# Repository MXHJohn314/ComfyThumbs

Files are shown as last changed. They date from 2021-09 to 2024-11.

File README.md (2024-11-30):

# ComfyThumbs

A column-staggered keyboard inspired by comfortable and efficient thumb use and keycap compatibility.

### The Default Keymap
<h5><b>Comfy Thumbs (v3)</b></h5>

[Check out the Gist on Keyboard Layout Editor](http://www.keyboard-layout-editor.com/#/gists/36e706f383088aca6e862086f8b5e326)
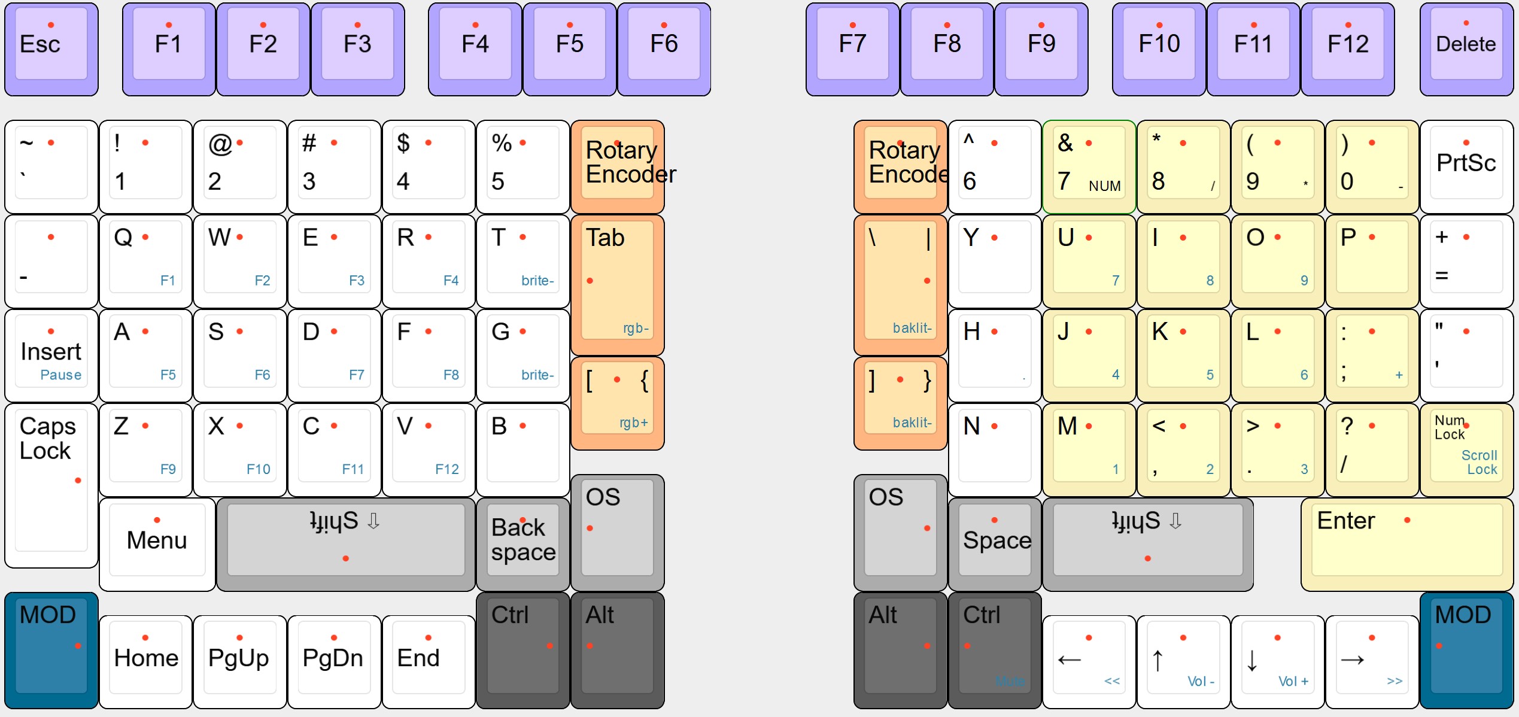
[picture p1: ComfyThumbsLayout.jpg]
Default Keymap

<p>

### High Keycap Compatibility

Comfy Thumbs has the highest keycap compatibility of any column-staggered board. Space and Backspace are the only keys that are not traditionally-sized. That means you won't need to buy/use different keycaps for `Right Shift`, `Left Shift`, `Enter`, `Tab`, `\ `, `Command`, `Ctrl`, `Alt`, `OS`, and `Application` keys. Just chose any Standard ANSI keycap set (99% of keycap sets), and you're good to go!. 

<p>

### Use your thumbs without hurting them

|Thumb Cluster Style|# of keys|Avg. reach from Home Position|
|---|---|---|
|ComfyThumbs|6|1u
|Manuform/Dactyl-Manuform|6|3.5u
|Maltron/Dacyl/Kenesis/Ergodox|6-8|4.5u

Unlike other large thumb cluster designs that waste valuable space by pushing the cluster away from resting thumb position or building the cluster on a convex plane, all thumb keys are within 1u radius of resting position. The thumbs naturally rest on either `Space` or `Backspace`, with `Shift`, `Ctrl`, `Alt` and `OS` nearby. There are two thumb rows; `Space`, `Backspace`, and both `Shift` keys have a higher profile on the upper thumb row to distinguish thumb location by feel.

### Comfy Thumbs = Comfy Pinkies
Your pinkies have been doing way more work than they should. That's why modifiers have moved to the thumb cluster. Adding to that, the index fingers have a new inner column for `Tab`, `\ `, `-`, `=`,  `[` and `]`.

Keyboard Maintainer: [MXHJohn314](https://mxhjohn314.github.io/)  

### Compiling the Firmware

See the [build environment setup](Todo) and the [make instructions](Todo) for more information. Brand new to ZMK? Start with our [Complete Newbs Guide](Todo).

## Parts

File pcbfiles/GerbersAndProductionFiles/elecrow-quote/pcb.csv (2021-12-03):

Id | Designator | Package | Quantity | Designation | Source/Manufacturer | Part # | Can substitute?
1 | SW59,SW82,SW2,SW56,SW20,SW3,SW11,SW61,SW78,SW89,SW52,SW67,SW41,SW72,SW88,SW87,SW86,SW85,SW83,SW81,SW80,SW79,SW77,SW76,SW75,SW74,SW71,SW70,SW69,SW68,SW65,SW64,SW63,SW62,SW60,SW58,SW57,SW55,SW54,SW53,SW49,SW48,SW39,SW37,SW36,SW35,SW34,SW33,SW31,SW30,SW29,SW28,SW27,SW25,SW24,SW23,SW22,SW21,SW19,SW18,SW17,SW16,SW15,SW14,SW13,SW12,SW10,SW9,SW8,SW7,SW6,SW5,SW4 | MXOnly-1U-Hotswap | 73 | SW_SPST | Kailhua | CPG151101S11 | No
6 | SW51 | MXOnly-2U-Hotswap-VerticalStabilizers | 1 | SW_SPST | Kailhua | CPG151101S11 | No
17 | SW73 | MXOnly-2.75U-Hotswap-ReversedStabilizers | 1 | SW_SPST | Kailhua | CPG151101S11 | No
18 | SW43 | MXOnly-1.75U-Hotswap | 1 | SW_SPST | Kailhua | CPG151101S11 | No
15 | SW91,SW90,SW84,SW45,SW40,SW32,SW42 | MXOnly-1.25U-Hotswap | 7 | SW_SPST | Kailhua | CPG151101S11 | No
19 | SW26 | MXOnly-2.25U-Hotswap-ReversedStabilizers | 1 | SW_SPST | Kailhua | CPG151101S11 | No
4 | SW44,SW50 | MXOnly-1.5U-Hotswap | 2 | SW_SPST | Kailhua | CPG151101S11 | No
2 | J10,J9,J5,J4 | JST_SH_SM05B-SRSS-TB_1x05-1MP_P1.00mm_Horizontal | 4 | Conn_01x05 | Japan Solderless Technologies | SM05B-SRSS-TB | No
5 | SW1,SW66 | SW_SPST_TL3342 | 2 | SW_SPST | E-Switch | TL3342F320QG | Yes
7 | U1,U4 | nRF52840_holyiot_18010_HS_simple | 2 | nRF52840_holyiot_18010 | I will source and supply these parts to Elecrow, for you to assemble. |  | N/A
8 | BT3,BT1 | JST_PH_S2B-PH-K_1x02_P2.00mm_Horizontal | 2 | Battery_Cell | Japan Solderless Technologies | S2B-PH-K-S | No
11 | D1,D60 | D_SOD-123 | 2 | 1N5819 | YFW | 1N5819W | Yes
12 | R15,R8 | R_0805_2012Metric | 2 | 2M | FH(Guangdong Fenghua Advanced Tech) | RS-05L2004FT | Yes
13 | R12,R16,R3,R2 | R_0805_2012Metric | 4 | 10k | RC0805JR-0710KL | YAGEO | Yes
16 | D56,D92,D91,D90,D89,D88,D87,D86,D85,D84,D83,D82,D81,D80,D79,D78,D77,D76,D75,D74,D73,D72,D71,D70,D69,D68,D67,D66,D65,D64,D63,D62,D61,D59,D58,D57,D55,D54,D53,D52,D51,D50,D49,D46,D45,D44,D43,D42,D41,D38,D37,D36,D35,D34,D33,D32,D31,D30,D29,D28,D27,D26,D25,D24,D23,D22,D21,D20,D19,D18,D17,D16,D15,D14,D13,D12,D11,D10,D9,D8,D7,D6,D5,D4,D3,D2 | D_SOD-123 | 86 | D_Small | MDD（Microdiode Electronics） | SM4007PL | Yes
20 | USB2,USB1 | HRO-TYPE-C-31-M-12-HandSoldering | 2 | HRO-TYPE-C-31-M-12 | Korean Hroparts Elec | TYPE-C-31-M-12 | No
21 | U6,U2 | SOT-23 | 2 | XC6206 | Torex Semicon | XC6206P332MR | Yes
22 | U5,U3 | SOT-23-5 | 2 | TP4054 | UMW(Youtai Semiconductor Co., Ltd.) | TP4054 | Yes
23 | SW47,SW38 | SW_SPDT_PCM12 | 2 | SW_SPDT | C&K | PCM12SMTR | Yes
24 | R14,R9 | R_0805_2012Metric | 2 | 1k | Resistor.Today | AECR0805F1K00K9 | Yes
25 | R13,R7 | R_0805_2012Metric | 2 | 806k | Walsin Tech Corp | WR08X8063FTL | Yes
26 | R11,R10,R5,R1 | R_0805_2012Metric | 4 | 5.1k | YAGEO | RC0805JR-075K1L | Yes
27 | R6,R4 | R_0805_2012Metric | 2 | 1M | TyoHM | RMC 0805 1M F N | Yes
28 | Q2,Q1 | SOT-23 | 2 | AO3401A | VBsemi Elec | AO3401A | Yes
29 | F2,F1 | Fuse_1206_3216Metric | 2 | 500ma | Littelfuse | 1206L050/15YR | Yes
30 | D48,D39 | D_0805_2012Metric | 2 | LED_Small | Hubei KENTO Elec | 17-21SUYC/TR8 | Yes
31 | D47,D40 | SOT-143 | 2 | SR05 | Leiditech | SR05 | Yes
32 | C8,C7,C4,C3 | C_0805_2012Metric | 4 | 1uF | Samsung Electro-Mechanics | CL21B105KBFNNNE | Yes
33 | C6,C1 | C_0805_2012Metric | 2 | 4.7uF | Samsung Electro-Mechanics | CL21B475KAFNNNE | Yes
34 | C5,C2 | C_0805_2012Metric | 2 | 4.7n | FH(Guangdong Fenghua Advanced Tech) | 0805B472K500NT | Yes

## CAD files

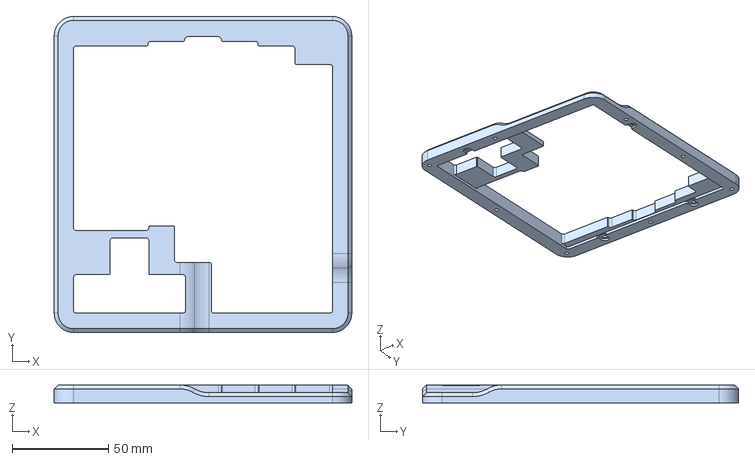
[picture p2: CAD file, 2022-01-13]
casefiles/case/left/TOP-LEFT-ComfyHands_prototype_13Jan.step
154.3 x 163.8 x 9.30 mm

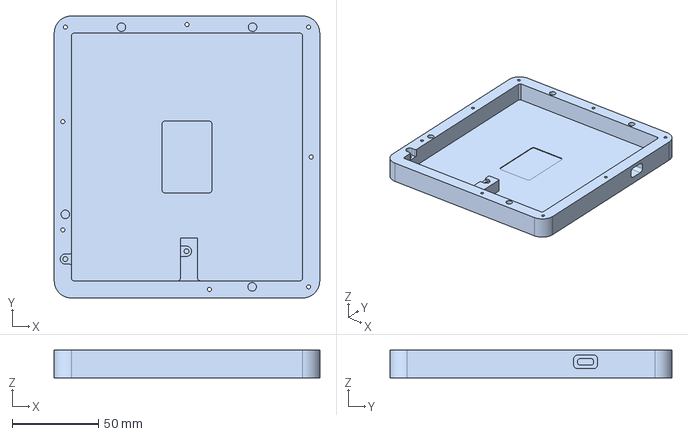
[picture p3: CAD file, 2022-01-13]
casefiles/case/right/BOTTOM-RIGHT-ComfyHands_prototype_13Jan.step
154.3 x 163.8 x 16.0 mm

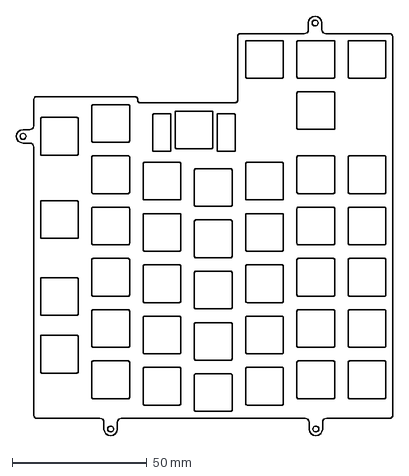
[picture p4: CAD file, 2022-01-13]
casefiles/plates/dxf/plate_left.dxf
139.8 x 155.9 mm

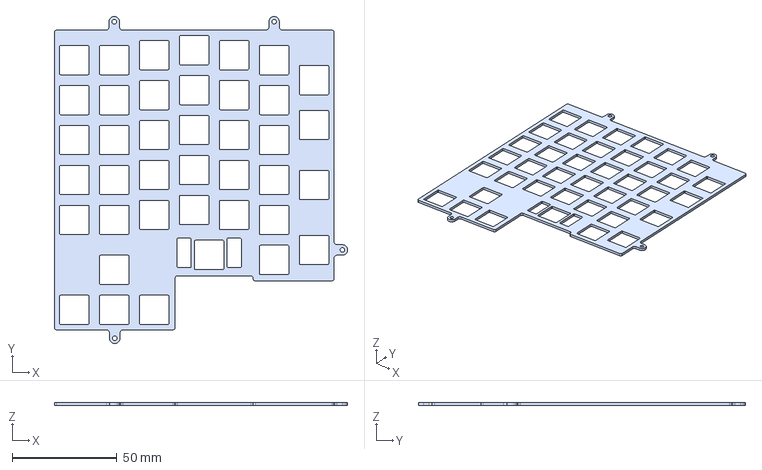
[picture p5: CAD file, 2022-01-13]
casefiles/plates/step/PLATE_LEFT-ComfyHands_prototype_13Jan.step
139.8 x 155.9 x 1.50 mm

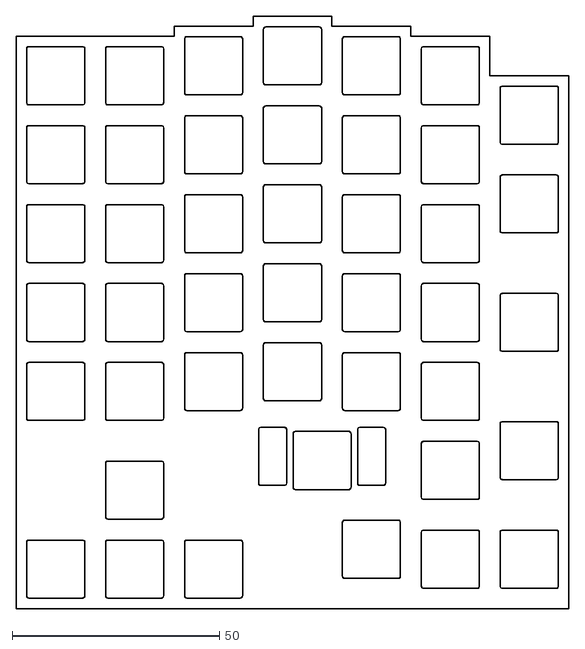
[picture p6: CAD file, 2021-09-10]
pcbfiles/plate-Edge_Cuts.dxf
133.3 x 142.9

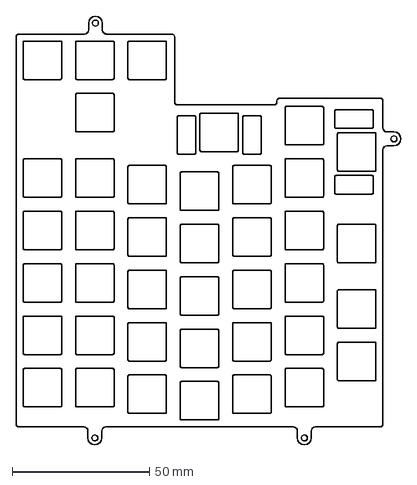
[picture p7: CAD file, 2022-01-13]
casefiles/plates/dxf/plate_right.dxf
139.8 x 155.9 mm

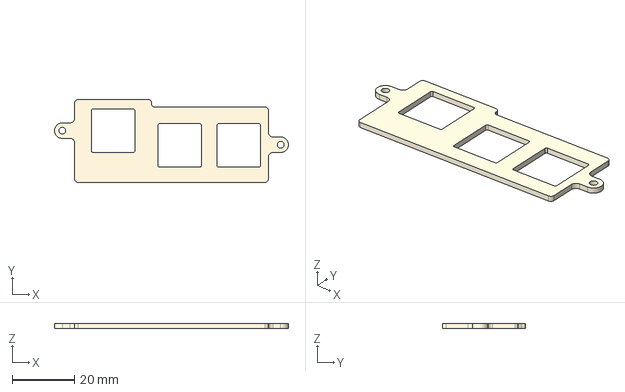
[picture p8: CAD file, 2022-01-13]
casefiles/plates/step/PLATE_SMALL-ComfyHands_prototype_13Jan.step
75.4 x 26.7 x 1.50 mm

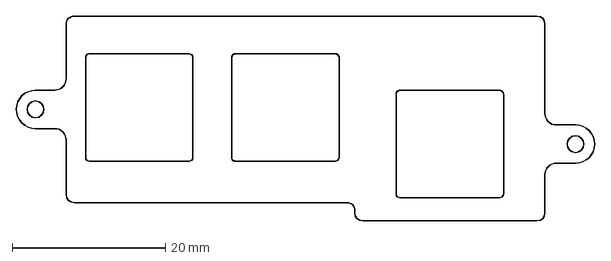
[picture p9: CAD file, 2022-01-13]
casefiles/plates/dxf/plate_small.dxf
75.4 x 26.7 mm

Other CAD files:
casefiles/case/left/BOTTOM-LEFT-ComfyHands_prototype_13Jan.step
casefiles/case/right/TOP-RIGHT-ComfyHands_prototype_13Jan.step
casefiles/plates/step/PLATE-RIGHT-ComfyHands_prototype_13Jan.step
casefiles/case/project.f3z

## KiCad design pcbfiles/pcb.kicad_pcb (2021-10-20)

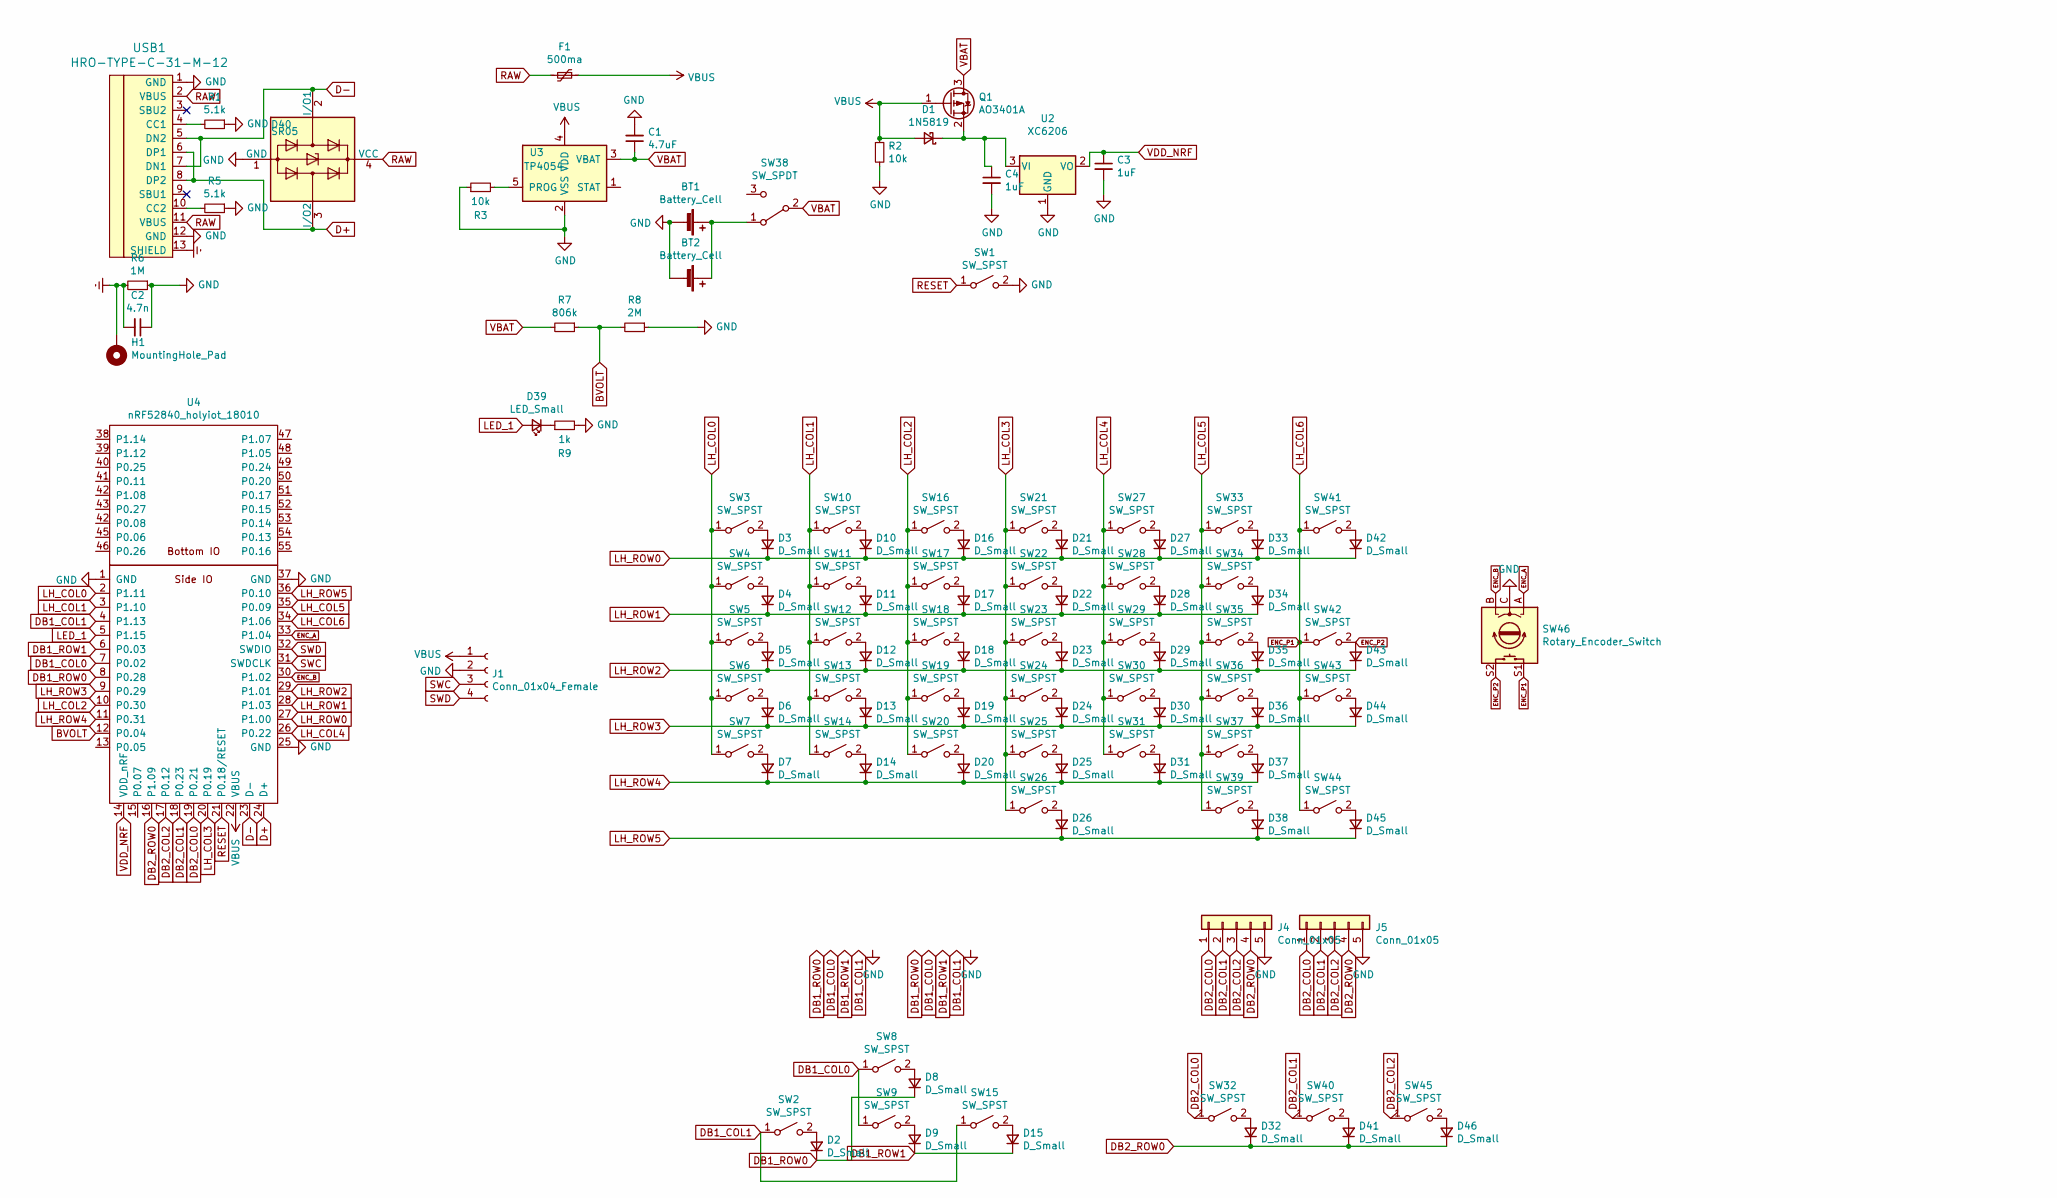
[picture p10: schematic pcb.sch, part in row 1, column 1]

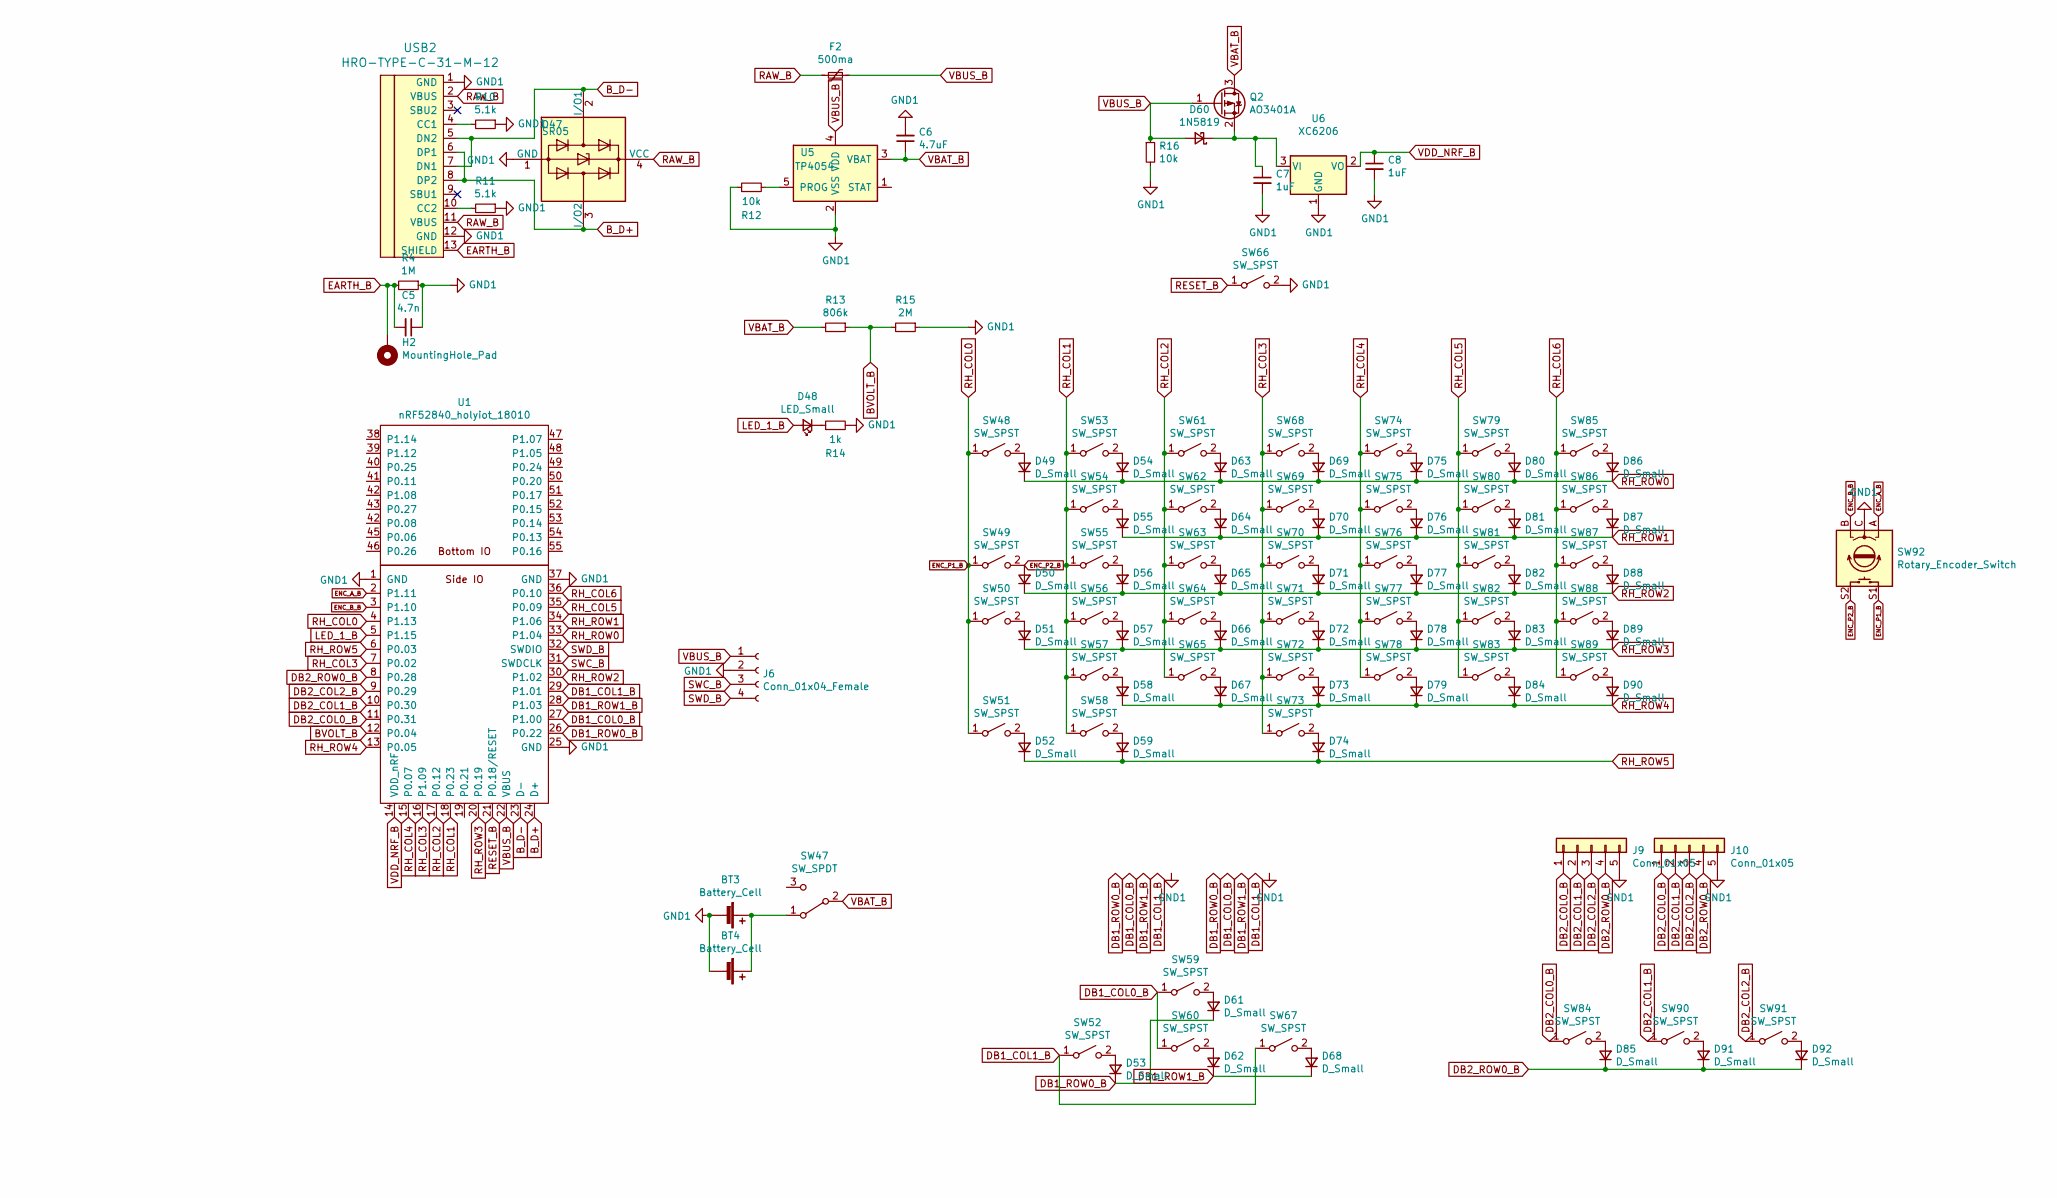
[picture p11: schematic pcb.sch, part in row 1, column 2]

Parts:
BT1, BT3: Battery_Cell; JST_PH_S2B-PH-K_1x02_P2.00mm_Horizontal
BT2, BT4: Battery_Cell; battery-custom-connector
C1, C6: 4.7uF; C_0805_2012Metric
C2, C5: 4.7n; C_0805_2012Metric
C3, C4, C7, C8: 1uF; C_0805_2012Metric
D1, D60: 1N5819; D_SOD-123
D2, D3, D4, D5, D6, D7, D8, D9, D10, D11, D12, D13, D14, D15, D16, D17, D18, D19, D20, D21, D22, D23, D24, D25, D26, D27, D28, D29, D30, D31, D32, D33, D34, D35, D36, D37, D38, D41, D42, D43, D44, D45, D46, D49, D50, D51, D52, D53, D54, D55, D56, D57, D58, D59, D61, D62, D63, D64, D65, D66, D67, D68, D69, D70, D71, D72, D73, D74, D75, D76, D77, D78, D79, D80, D81, D82, D83, D84, D85, D86, D87, D88, D89, D90, D91, D92: D_Small; D_SOD-123
D39, D48: LED_Small; D_0805_2012Metric
D40, D47: SR05; SOT-143
F1, F2: 500ma; Fuse_1206_3216Metric
H1, H2: MountingHole_Pad
J1, J6: Conn_01x04_Female; PinHeader_1x04_P2.54mm_Vertical
J4, J5, J9, J10: Conn_01x05; JST_SH_SM05B-SRSS-TB_1x05-1MP_P1.00mm_Horizontal
Q1, Q2: AO3401A; SOT-23
R1, R5, R10, R11: 5.1k; R_0805_2012Metric
R2, R3, R12, R16: 10k; R_0805_2012Metric
R4, R6: 1M; R_0805_2012Metric
R7, R13: 806k; R_0805_2012Metric
R8, R15: 2M; R_0805_2012Metric
R9, R14: 1k; R_0805_2012Metric
SW1, SW66: SW_SPST; SW_SPST_TL3342
SW2, SW3, SW4, SW5, SW6, SW7, SW8, SW9, SW10, SW11, SW12, SW13, SW14, SW15, SW16, SW17, SW18, SW19, SW20, SW21, SW22, SW23, SW24, SW25, SW27, SW28, SW29, SW30, SW31, SW33, SW34, SW35, SW36, SW37, SW39, SW41, SW48, SW49, SW52, SW53, SW54, SW55, SW56, SW57, SW58, SW59, SW60, SW61, SW62, SW63, SW64, SW65, SW67, SW68, SW69, SW70, SW71, SW72, SW74, SW75, SW76, SW77, SW78, SW79, SW80, SW81, SW82, SW83, SW85, SW86, SW87, SW88, SW89: SW_SPST; MXOnly-1U-Hotswap
SW26: SW_SPST; MXOnly-2.25U-Hotswap-ReversedStabilizers
SW32, SW40, SW42, SW45, SW84, SW90, SW91: SW_SPST; MXOnly-1.25U-Hotswap
SW38, SW47: SW_SPDT; SW_SPDT_PCM12
SW43: SW_SPST; MXOnly-1.75U-Hotswap
SW44, SW50: SW_SPST; MXOnly-1.5U-Hotswap
SW46, SW92: Rotary_Encoder_Switch; RotaryEncoder_Alps_EC11E-Switch_Vertical_H20mm
SW51: SW_SPST; MXOnly-2U-Hotswap-VerticalStabilizers
SW73: SW_SPST; MXOnly-2.75U-Hotswap-ReversedStabilizers
U1, U4: nRF52840_holyiot_18010; nRF52840_holyiot_18010_HS_simple
U2, U6: XC6206; SOT-23
U3, U5: TP4054; SOT-23-5
USB1, USB2: HRO-TYPE-C-31-M-12; HRO-TYPE-C-31-M-12-HandSoldering

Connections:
BVOLT: R7.1, R8.2, U4.12 (P0.04)
BVOLT_B: R13.1, R15.2, U1.12 (P0.04)
B_D+: D47.3 (I/O2), U1.24 (D+), USB2.6 (DP1), USB2.8 (DP2)
B_D-: D47.2 (I/O1), U1.23 (D-), USB2.5 (DN2), USB2.7 (DN1)
D+: D40.3 (I/O2), U4.24 (D+), USB1.6 (DP1), USB1.8 (DP2)
D-: D40.2 (I/O1), U4.23 (D-), USB1.5 (DN2), USB1.7 (DN1)
DB1_COL0: SW8.1 (A), SW9.1 (A), U4.7 (P0.02)
DB1_COL0_B: SW59.1 (A), SW60.1 (A), U1.27 (P1.00)
DB1_COL1: SW2.1 (A), SW15.1 (A), U4.4 (P1.13)
DB1_COL1_B: SW52.1 (A), SW67.1 (A), U1.29 (P1.01)
DB1_ROW0: D2.1 (K), D8.1 (K), U4.8 (P0.28)
DB1_ROW0_B: D53.1 (K), D61.1 (K), U1.26 (P0.22)
DB1_ROW1: D9.1 (K), D15.1 (K), U4.6 (P0.03)
DB1_ROW1_B: D62.1 (K), D68.1 (K), U1.28 (P1.03)
DB2_COL0: J4.1, J5.1, SW32.1 (A), U4.19 (P0.21)
DB2_COL0_B: J9.1, J10.1, SW84.1 (A), U1.11 (P0.31)
DB2_COL1: J4.2, J5.2, SW40.1 (A), U4.18 (P0.23)
DB2_COL1_B: J9.2, J10.2, SW90.1 (A), U1.10 (P0.30)
DB2_COL2: J4.3, J5.3, SW45.1 (A), U4.17 (P0.12)
DB2_COL2_B: J9.3, J10.3, SW91.1 (A), U1.9 (P0.29)
DB2_ROW0: D32.1 (K), D41.1 (K), D46.1 (K), J4.4, J5.4, U4.16 (P1.09)
DB2_ROW0_B: D85.1 (K), D91.1 (K), D92.1 (K), J9.4, J10.4, U1.8 (P0.28)
EARTH_B: C5.2, H2.1, R4.2, USB2.13 (SHIELD)
ENC_A: SW46.A, U4.33 (P1.04)
ENC_A_B: SW92.A, U1.2 (P1.11)
ENC_B: SW46.B, U4.30 (P1.02)
ENC_B_B: SW92.B, U1.3 (P1.10)
ENC_P1: SW41.1 (A), SW42.1 (A), SW43.1 (A), SW44.1 (A), SW46.S1, U4.34 (P1.06)
ENC_P1_B: SW48.1 (A), SW49.1 (A), SW50.1 (A), SW51.1 (A), SW92.S1, U1.4 (P1.13)
ENC_P2: D43.2 (A), SW42.2 (B), SW46.S2
ENC_P2_B: D50.2 (A), SW49.2 (B), SW92.S2
Earth: C2.2, H1.1, R6.2, USB1.13 (SHIELD)
GND: BT1.2 (-), BT2.2 (-), C1.2, C2.1, C3.2, C4.2, D40.1 (GND), J1.2, J4.5, J5.5, R1.1, R2.2, R3.1, R5.1, R6.1, R8.1, R9.2, SW1.2 (B), SW46.C, U2.1 (GND), U3.2 (VSS), U4.1 (GND), U4.25 (GND), U4.37 (GND), USB1.1 (GND), USB1.12 (GND)
GND1: BT3.2 (-), BT4.2 (-), C5.1, C6.2, C7.2, C8.2, D47.1 (GND), J6.2, J9.5, J10.5, R4.1, R10.1, R11.1, R12.1, R14.2, R15.1, R16.2, SW66.2 (B), SW92.C, U1.1 (GND), U1.25 (GND), U1.37 (GND), U5.2 (VSS), U6.1 (GND), USB2.1 (GND), USB2.12 (GND)
LED_1: D39.2 (A), U4.5 (P1.15)
LED_1_B: D48.2 (A), U1.5 (P1.15)
LH_COL0: SW3.1 (A), SW4.1 (A), SW5.1 (A), SW6.1 (A), SW7.1 (A), U4.2 (P1.11)
LH_COL1: SW10.1 (A), SW11.1 (A), SW12.1 (A), SW13.1 (A), SW14.1 (A), U4.3 (P1.10)
LH_COL2: SW16.1 (A), SW17.1 (A), SW18.1 (A), SW19.1 (A), SW20.1 (A), U4.10 (P0.30)
LH_COL3: SW21.1 (A), SW22.1 (A), SW23.1 (A), SW24.1 (A), SW25.1 (A), SW26.1 (A), U4.20 (P0.19)
LH_COL4: SW27.1 (A), SW28.1 (A), SW29.1 (A), SW30.1 (A), SW31.1 (A), U4.26 (P0.22)
LH_COL5: SW33.1 (A), SW34.1 (A), SW35.1 (A), SW36.1 (A), SW37.1 (A), SW39.1 (A), U4.35 (P0.09)
LH_ROW0: D3.1 (K), D10.1 (K), D16.1 (K), D21.1 (K), D27.1 (K), D33.1 (K), D42.1 (K), U4.27 (P1.00)
LH_ROW1: D4.1 (K), D11.1 (K), D17.1 (K), D22.1 (K), D28.1 (K), D34.1 (K), U4.28 (P1.03)
LH_ROW2: D5.1 (K), D12.1 (K), D18.1 (K), D23.1 (K), D29.1 (K), D35.1 (K), D43.1 (K), U4.29 (P1.01)
LH_ROW3: D6.1 (K), D13.1 (K), D19.1 (K), D24.1 (K), D30.1 (K), D36.1 (K), D44.1 (K), U4.9 (P0.29)
LH_ROW4: D7.1 (K), D14.1 (K), D20.1 (K), D25.1 (K), D31.1 (K), D37.1 (K), U4.11 (P0.31)
LH_ROW5: D26.1 (K), D38.1 (K), D45.1 (K), U4.36 (P0.10)
unnamed: BT1.1 (+), BT2.1 (+), SW38.1 (A)
unnamed: BT3.1 (+), BT4.1 (+), SW47.1 (A)
unnamed: C4.1, D1.1 (K), Q1.2 (S), U2.3 (VI)
unnamed: C7.1, D60.1 (K), Q2.2 (S), U6.3 (VI)
unnamed: D2.2 (A), SW2.2 (B)
unnamed: D3.2 (A), SW3.2 (B)
unnamed: D4.2 (A), SW4.2 (B)
unnamed: D5.2 (A), SW5.2 (B)
unnamed: D6.2 (A), SW6.2 (B)
unnamed: D7.2 (A), SW7.2 (B)
unnamed: D8.2 (A), SW8.2 (B)
unnamed: D9.2 (A), SW9.2 (B)
unnamed: D10.2 (A), SW10.2 (B)
unnamed: D11.2 (A), SW11.2 (B)
unnamed: D12.2 (A), SW12.2 (B)
unnamed: D13.2 (A), SW13.2 (B)
unnamed: D14.2 (A), SW14.2 (B)
unnamed: D15.2 (A), SW15.2 (B)
unnamed: D16.2 (A), SW16.2 (B)
unnamed: D17.2 (A), SW17.2 (B)
unnamed: D18.2 (A), SW18.2 (B)
unnamed: D19.2 (A), SW19.2 (B)
unnamed: D20.2 (A), SW20.2 (B)
unnamed: D21.2 (A), SW21.2 (B)
unnamed: D22.2 (A), SW22.2 (B)
unnamed: D23.2 (A), SW23.2 (B)
unnamed: D24.2 (A), SW24.2 (B)
unnamed: D25.2 (A), SW25.2 (B)
unnamed: D26.2 (A), SW26.2 (B)
unnamed: D27.2 (A), SW27.2 (B)
unnamed: D28.2 (A), SW28.2 (B)
unnamed: D29.2 (A), SW29.2 (B)
unnamed: D30.2 (A), SW30.2 (B)
unnamed: D31.2 (A), SW31.2 (B)
unnamed: D32.2 (A), SW32.2 (B)
unnamed: D33.2 (A), SW33.2 (B)
unnamed: D34.2 (A), SW34.2 (B)
unnamed: D35.2 (A), SW35.2 (B)
unnamed: D36.2 (A), SW36.2 (B)
unnamed: D37.2 (A), SW37.2 (B)
unnamed: D38.2 (A), SW39.2 (B)
unnamed: D39.1 (K), R9.1
unnamed: D41.2 (A), SW40.2 (B)
unnamed: D42.2 (A), SW41.2 (B)
unnamed: D44.2 (A), SW43.2 (B)
unnamed: D45.2 (A), SW44.2 (B)
unnamed: D46.2 (A), SW45.2 (B)
unnamed: D48.1 (K), R14.1
unnamed: D49.2 (A), SW48.2 (B)
unnamed: D51.2 (A), SW50.2 (B)
unnamed: D52.2 (A), SW51.2 (B)
unnamed: D53.2 (A), SW52.2 (B)
unnamed: D54.2 (A), SW53.2 (B)
unnamed: D55.2 (A), SW54.2 (B)
unnamed: D56.2 (A), SW55.2 (B)
unnamed: D57.2 (A), SW56.2 (B)
unnamed: D58.2 (A), SW57.2 (B)
unnamed: D59.2 (A), SW58.2 (B)
unnamed: D61.2 (A), SW59.2 (B)
unnamed: D62.2 (A), SW60.2 (B)
unnamed: D63.2 (A), SW61.2 (B)
unnamed: D64.2 (A), SW62.2 (B)
unnamed: D65.2 (A), SW63.2 (B)
unnamed: D66.2 (A), SW64.2 (B)
unnamed: D67.2 (A), SW65.2 (B)
unnamed: D68.2 (A), SW67.2 (B)
unnamed: D69.2 (A), SW68.2 (B)
unnamed: D70.2 (A), SW69.2 (B)
unnamed: D71.2 (A), SW70.2 (B)
unnamed: D72.2 (A), SW71.2 (B)
unnamed: D73.2 (A), SW72.2 (B)
unnamed: D74.2 (A), SW73.2 (B)
unnamed: D75.2 (A), SW74.2 (B)
unnamed: D76.2 (A), SW75.2 (B)
unnamed: D77.2 (A), SW76.2 (B)
unnamed: D78.2 (A), SW77.2 (B)
unnamed: D79.2 (A), SW78.2 (B)
unnamed: D80.2 (A), SW79.2 (B)
unnamed: D81.2 (A), SW80.2 (B)
unnamed: D82.2 (A), SW81.2 (B)
unnamed: D83.2 (A), SW82.2 (B)
unnamed: D84.2 (A), SW83.2 (B)
unnamed: D85.2 (A), SW84.2 (B)
unnamed: D86.2 (A), SW85.2 (B)
unnamed: D87.2 (A), SW86.2 (B)
unnamed: D88.2 (A), SW87.2 (B)
unnamed: D89.2 (A), SW88.2 (B)
unnamed: D90.2 (A), SW89.2 (B)
unnamed: D91.2 (A), SW90.2 (B)
unnamed: D92.2 (A), SW91.2 (B)
unnamed: R1.2, USB1.4 (CC1)
unnamed: R3.2, U3.5 (PROG)
unnamed: R5.2, USB1.10 (CC2)
unnamed: R10.2, USB2.4 (CC1)
unnamed: R11.2, USB2.10 (CC2)
unnamed: R12.2, U5.5 (PROG)
RAW: D40.4 (VCC), F1.2, USB1.2 (VBUS), USB1.11 (VBUS)
RAW_B: D47.4 (VCC), F2.2, USB2.2 (VBUS), USB2.11 (VBUS)
RESET: SW1.1 (A), U4.21 (P0.18/RESET)
RESET_B: SW66.1 (A), U1.21 (P0.18/RESET)
RH_COL1: SW53.1 (A), SW54.1 (A), SW55.1 (A), SW56.1 (A), SW57.1 (A), SW58.1 (A), U1.18 (P0.23)
RH_COL2: SW61.1 (A), SW62.1 (A), SW63.1 (A), SW64.1 (A), SW65.1 (A), U1.17 (P0.12)
RH_COL3: SW68.1 (A), SW69.1 (A), SW70.1 (A), SW71.1 (A), SW72.1 (A), SW73.1 (A), U1.7 (P0.02), U1.16 (P1.09)
RH_COL4: SW74.1 (A), SW75.1 (A), SW76.1 (A), SW77.1 (A), SW78.1 (A), U1.15 (P0.07)
RH_COL5: SW79.1 (A), SW80.1 (A), SW81.1 (A), SW82.1 (A), SW83.1 (A), U1.35 (P0.09)
RH_COL6: SW85.1 (A), SW86.1 (A), SW87.1 (A), SW88.1 (A), SW89.1 (A), U1.36 (P0.10)
RH_ROW0: D49.1 (K), D54.1 (K), D63.1 (K), D69.1 (K), D75.1 (K), D80.1 (K), D86.1 (K), U1.33 (P1.04)
RH_ROW1: D55.1 (K), D64.1 (K), D70.1 (K), D76.1 (K), D81.1 (K), D87.1 (K), U1.34 (P1.06)
RH_ROW2: D50.1 (K), D56.1 (K), D65.1 (K), D71.1 (K), D77.1 (K), D82.1 (K), D88.1 (K), U1.30 (P1.02)
RH_ROW3: D51.1 (K), D57.1 (K), D66.1 (K), D72.1 (K), D78.1 (K), D83.1 (K), D89.1 (K), U1.20 (P0.19)
RH_ROW4: D58.1 (K), D67.1 (K), D73.1 (K), D79.1 (K), D84.1 (K), D90.1 (K), U1.13 (P0.05)
RH_ROW5: D52.1 (K), D59.1 (K), D74.1 (K), U1.6 (P0.03)
SWC: J1.3, U4.31 (SWDCLK)
SWC_B: J6.3, U1.31 (SWDCLK)
SWD: J1.4, U4.32 (SWDIO)
SWD_B: J6.4, U1.32 (SWDIO)
VBAT: C1.1, Q1.3 (D), R7.2, SW38.2 (B), U3.3 (VBAT)
VBAT_B: C6.1, Q2.3 (D), R13.2, SW47.2 (B), U5.3 (VBAT)
VBUS: D1.2 (A), F1.1, J1.1, Q1.1 (G), R2.1, U3.4 (VDD), U4.22 (VBUS)
VBUS_B: D60.2 (A), F2.1, J6.1, Q2.1 (G), R16.1, U1.22 (VBUS), U5.4 (VDD)
VDD_NRF: C3.1, U2.2 (VO), U4.14 (VDD_nRF)
VDD_NRF_B: C8.1, U1.14 (VDD_nRF), U6.2 (VO)

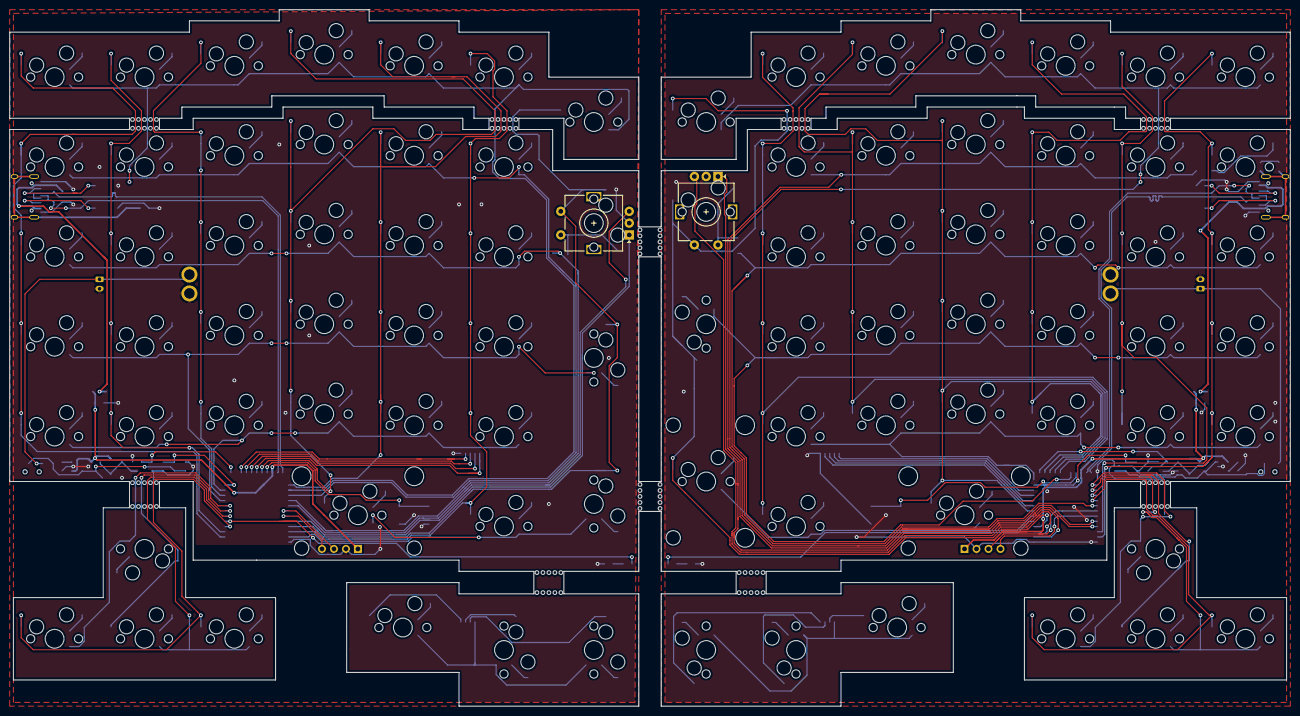
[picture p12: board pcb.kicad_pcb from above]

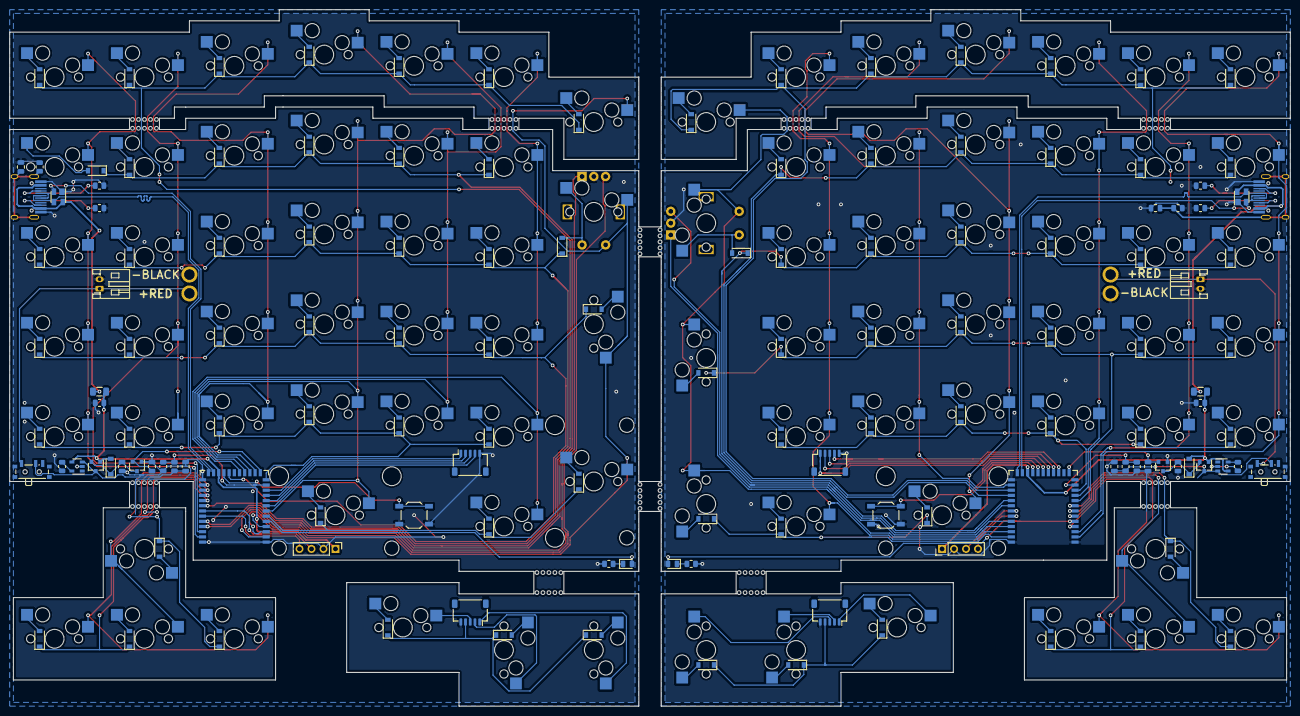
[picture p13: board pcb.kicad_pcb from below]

Board: 2 copper layers, 271.5 x 147.6 mm, 230 parts (140 on the bottom side), 170 nets.

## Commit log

2021-08-16 Create KiCad project, incomplete schematic
    KiCad project created, library submodules added, add gitignore, start schematic (split design, no matrix).
    [pcb.kicad_pcb, pcb.sch]
2021-08-18 continue schematic, test pcb idea
    [pcb.kicad_pcb, pcb.sch]
2021-08-21 PCB Layout, Diodes, Matrix
    Main body switches placed, some parts of matrix routed, PCB progress.
    [pcb.kicad_pcb, pcb.sch]
2021-08-22 Various commits
    I can't remember exactly what's changed since last time, but this is the most recent version!
    [pcb.kicad_pcb, pcb.sch]
2021-08-24 Various changes, finished placing switches
    [pcb.kicad_pcb, pcb.sch]
2021-08-25 Place components in new arrangement
    [pcb.kicad_pcb, pcb.sch]
2021-08-25 Further placement of parts
    [pcb.kicad_pcb, pcb.sch]
2021-08-28 USB wiring, etc...
    [pcb.kicad_pcb, pcb.sch]
2021-08-28 More wiring.
    [pcb.kicad_pcb]
2021-08-29 Various changes.
    [pcb.kicad_pcb, pcb.sch]
2021-08-30 Final commit for the day.
    [pcb-Edge_Cuts.dxf, pcb.kicad_pcb, pcb.sch]
2021-09-02 Step file, various kinds of progress.
    [pcb.kicad_pcb, pcb.sch]
2021-09-02 Added dxf files and case folder
    [comfy_thumbs_left.dxf, comfy_thumbs_right.dxf]
2021-09-03 PCB progress
    [pcb.kicad_pcb]
2021-09-04 Routing progress.
    [pcb.sch]
2021-09-04 More progress.
    [pcb.kicad_pcb]
2021-09-04 more routing
    [pcb.kicad_pcb, pcb.sch]
2021-09-05 Save most recent routing.
    [pcb.kicad_pcb, pcb.sch]
2021-09-06 Finish all basic routing!
    [pcb.kicad_pcb, pcb.sch]
2021-09-06 Forgot to save the work I thought I had...
    [pcb.kicad_pcb]
2021-09-07 Save work.
    [plate.kicad_pcb]
2021-09-07 These libraries made my KiCad crash.
2021-09-07 updated left and right plates using ai03 plate generator
    [comfy_thumbs_left.dxf, comfy_thumbs_right.dxf]
2021-09-10 Almost there!
    [pcb.kicad_pcb, pcb.sch, plate-Edge_Cuts.dxf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]
2021-09-10 Forgot to save before commit.
    [pcb.kicad_pcb]
2021-09-12 finished commit sans production files
    [pcb.kicad_pcb, pcb.sch]
2021-09-12 Final! PCBs were ordered based off this commit.
    [jlcbom.csv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]
2021-10-20 remove JST for thumb keys and move batt connector
    [pcb.kicad_pcb, pcb.sch]
2021-10-20 minor changes, production files
    [pcb-B_Cu.gbl, pcb-B_Mask.gbs, pcb-B_SilkS.gbo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]
2021-10-20 updated step file
    [pcb.kicad_pcb]
2022-01-12 Plate file updates, cleanup
    [comfy_thumbs_left.dxf, comfy_thumbs_right.dxf, pcb-Edge_Cuts.dxf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]
2022-01-13 Restructure, add case files
    [BOTTOM-LEFT-ComfyHands_prototype_13Jan.step, BOTTOM-RIGHT-ComfyHands_prototype_13Jan.step, PLATE-RIGHT-ComfyHands_prototype_13Jan.step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]
2022-01-13 - Changed Fusion360 project name for case design from "TheComfyHands_BothFullyBuilt.f3z" to "project.f3z"
    [project.f3z]
